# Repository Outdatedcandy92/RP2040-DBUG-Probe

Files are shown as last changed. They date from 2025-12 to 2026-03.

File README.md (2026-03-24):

# RP2040 DBUG Probe

A RP2040 based debug probe; A USB device that provides a UART serial port and SWD interface.
Inspired by the [Raspberry Pi Debug Probe](https://www.raspberrypi.com/documentation/microcontrollers/debug-probe.html) I wanted to make my own debug probe as a fun project but implement custom features like a Type-C connector and regular (non JST) connectors while still keeping the original board footprint.

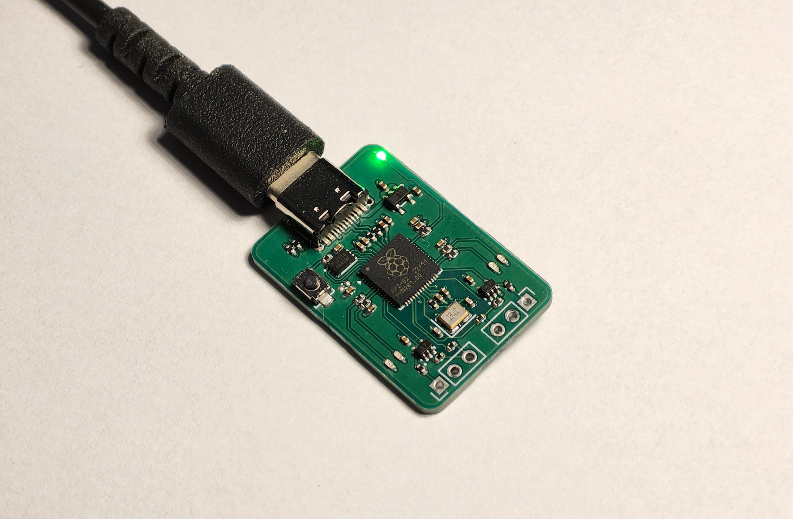
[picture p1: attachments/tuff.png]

## Features

- RP2040 MCU (Duh)
- 16Mbit Flash
- USB-C Connector 
- 32mm X 22mm Board Footprint
- USB to UART/SWD Interfaces With Level Shifters
- Uses regular 2.54mm Pitch Headers
- Status LEDs for serial interfaces and power

## Table of Contents

- [Overview](#rp2040-dbug-probe)
- [Quick Start](#quick-start)
- [Hardware](#hardware)
	- [Pinout](#pinout)
	- [Schematic](#schematic)
	- [PCB](#pcb)
	- [Case](#case)
	- [BOM/Reproduction](#bomreproduction)
- [Firmware](#firmware)
- [License](#license)

## Quick Start

1. Hold the button on the board while plugging in the USB-C cable.
2. The board will appear as a mass storage device.
3. Drag and drop the `debugprobe.uf2` file from `/firmware` onto the device.

The RP2040 will reboot, and the status LED should turn green. It’s now ready to use as a USB-to-UART/SWD bridge.

To use it as a USB-to-UART adapter, open the corresponding COM port in your preferred tool and start communicating.

## Hardware

### Pinout

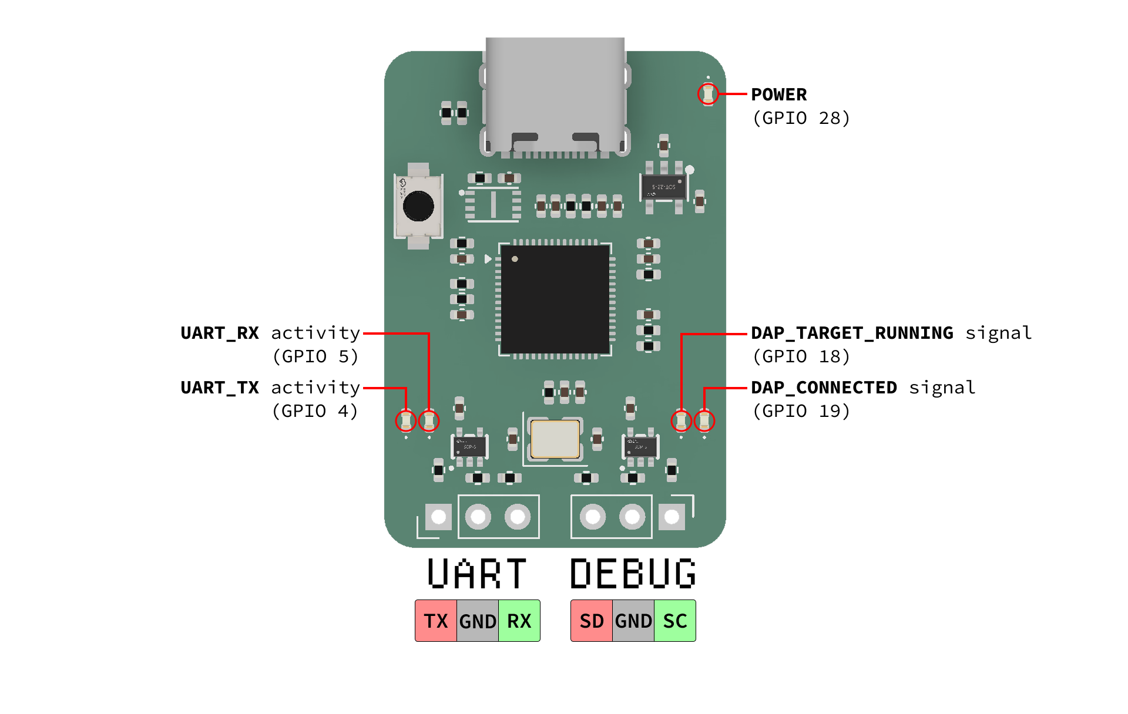
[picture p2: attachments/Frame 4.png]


### Schematic

Schematic pdf is available under the `/hardware/PCB` folder and the project's KiCad files can be found under `/hardware/PCB/kicad`.

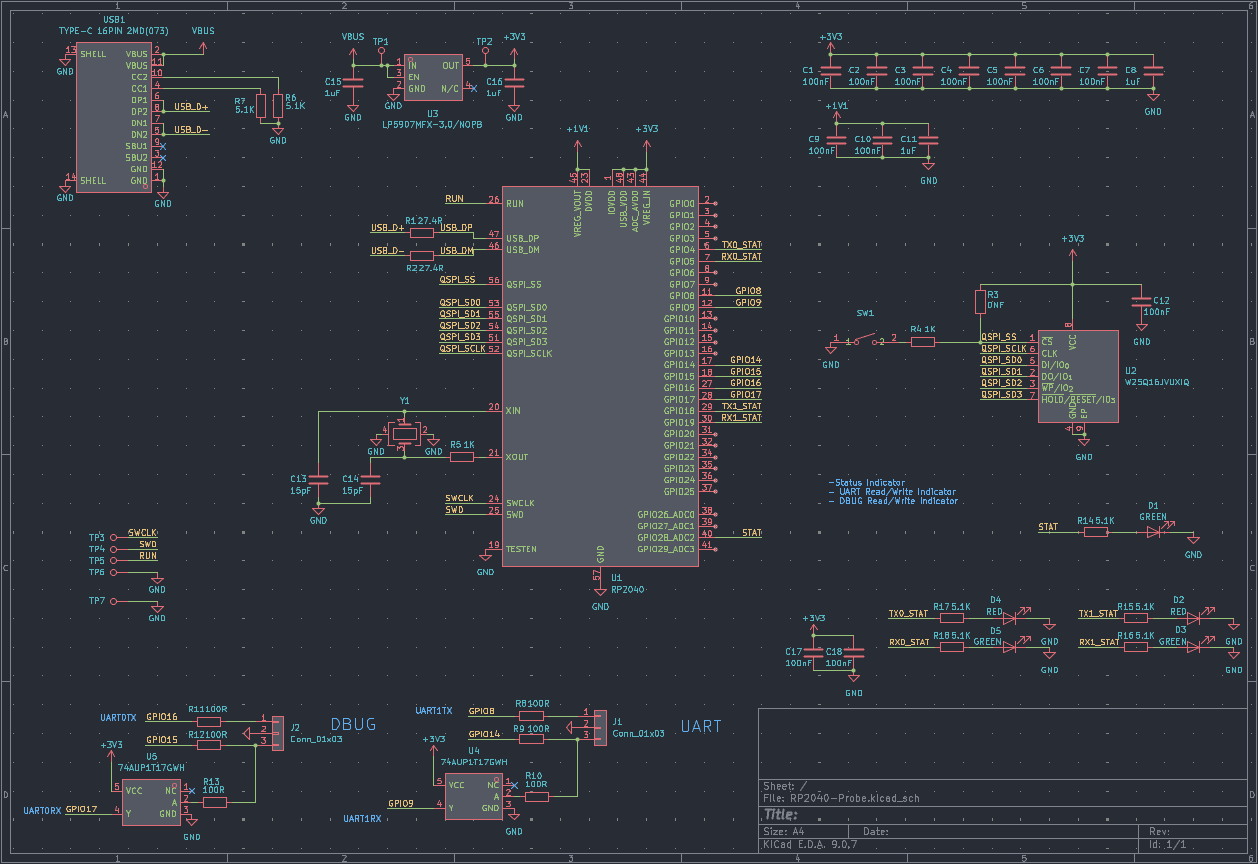
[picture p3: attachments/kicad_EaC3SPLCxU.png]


### PCB

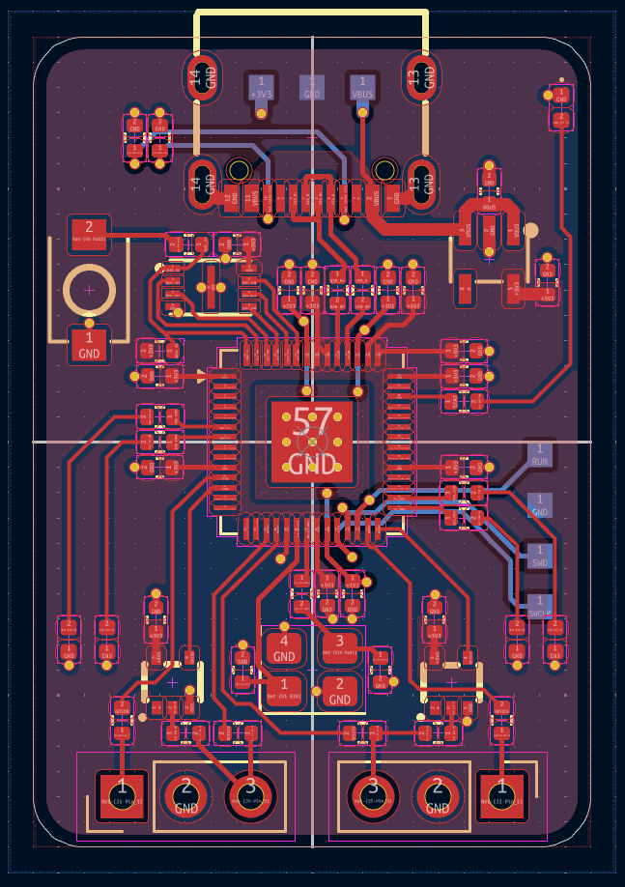
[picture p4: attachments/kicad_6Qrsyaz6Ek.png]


### Case

The case files can be found under `/hardware/case`, It includes the STEP assembly file, and STLs for printing. 
Use the `top.stl` and `logo.stl` if you want to have the logo printed on top, if not use the `top_no_logo.stl`.

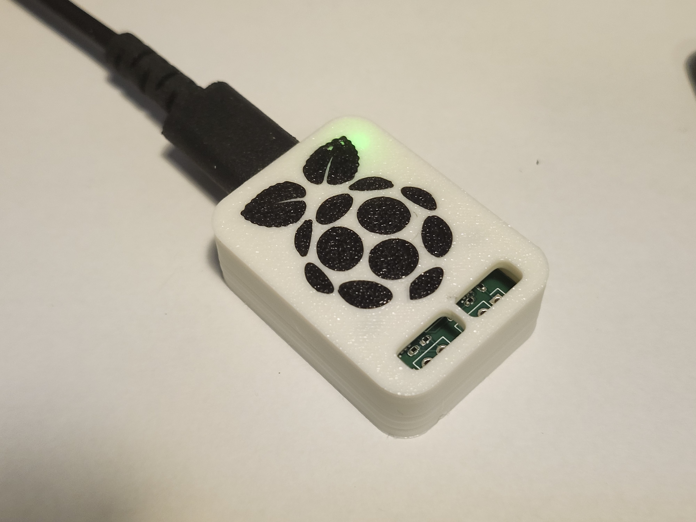
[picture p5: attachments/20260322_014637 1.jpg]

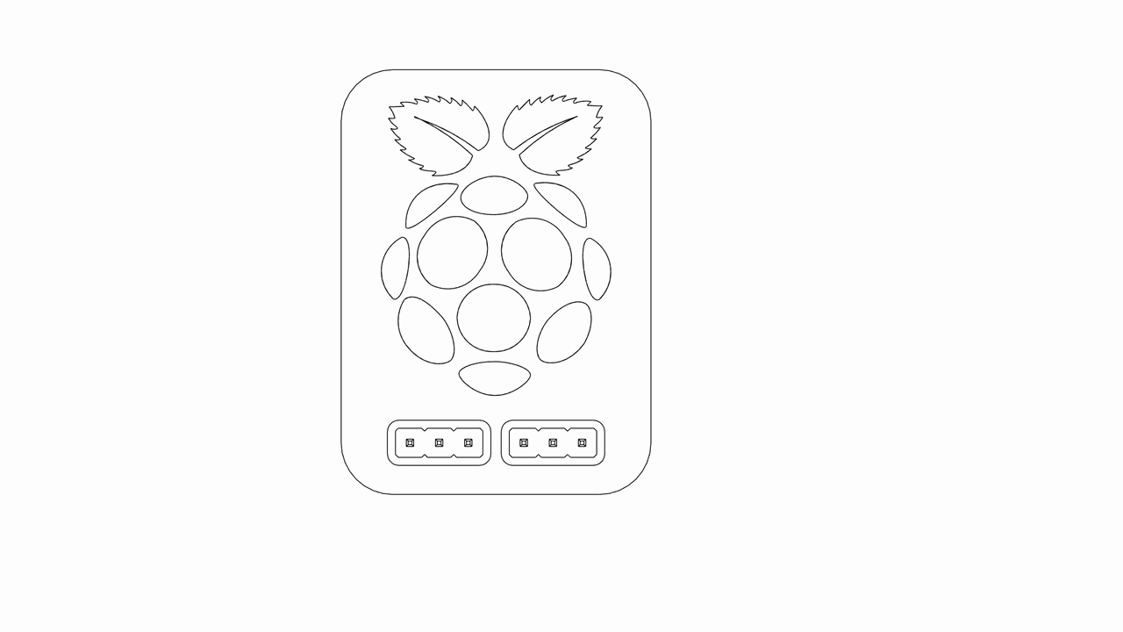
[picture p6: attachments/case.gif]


### BOM/Reproduction

The rough BOM can be found in [BOM.md](./BOM.md) and it assumes you'll assemble the board yourself. The rough cost for just the PCB and parts (excluding shipping) is around $24.

To build one yourself, use the files in `/hardware/production` to order the PCB and components, or opt for PCBA.

## Firmware

This project uses the [Debugprobe](https://github.com/raspberrypi/debugprobe?tab=readme-ov-file) firmware. To build one yourself for this board:

1. Clone the debug probe repository, cd into it and update the submodules.

```
git clone https://github.com/raspberrypi/debugprobe
cd debugprobe
git submodule update --init --recursive
```

2. Open  `/include/board_debug_probe_config.h` and edit the pin definitions to match the board.
   
3. Make a build directory and cd into it.

```
 mkdir build
 cd build
```

4. Run cmake and build the code.

>If your environment doesn't contain `PICO_SDK_PATH`, then either add it to your environment variables with `export PICO_SDK_PATH=/path/to/sdk` or add `-DPICO_SDK_PATH=/path/to/sdk` to the arguments to CMake below.

```
 cmake ..
 make
```

Once it successfully builds you should have a `debugprobe.uf2` file that you can upload to the board.

---

## License

This project is licensed under the CERN Open Hardware Licence Version 2 Weakly Reciprocal [(CERN OHL W)](LICENSE.txt)

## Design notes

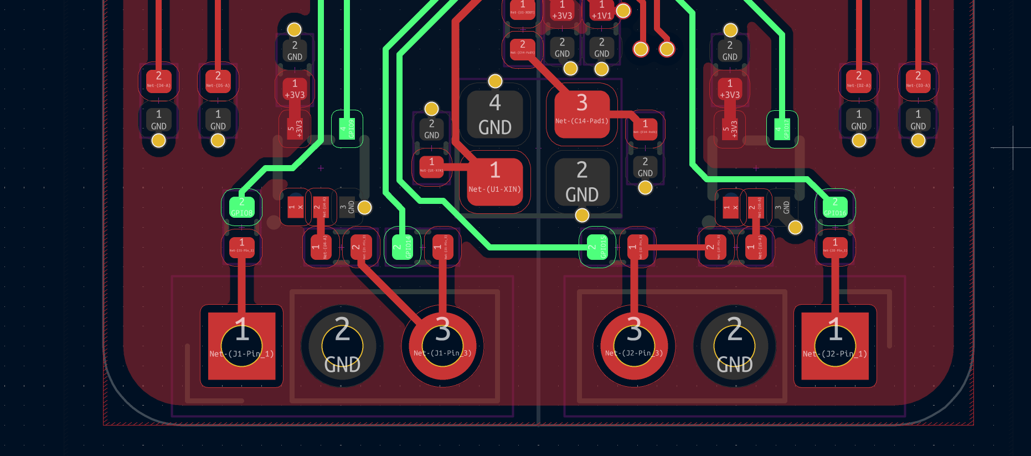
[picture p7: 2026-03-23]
attachments/Screenshot 2025-12-25 191721 1.png

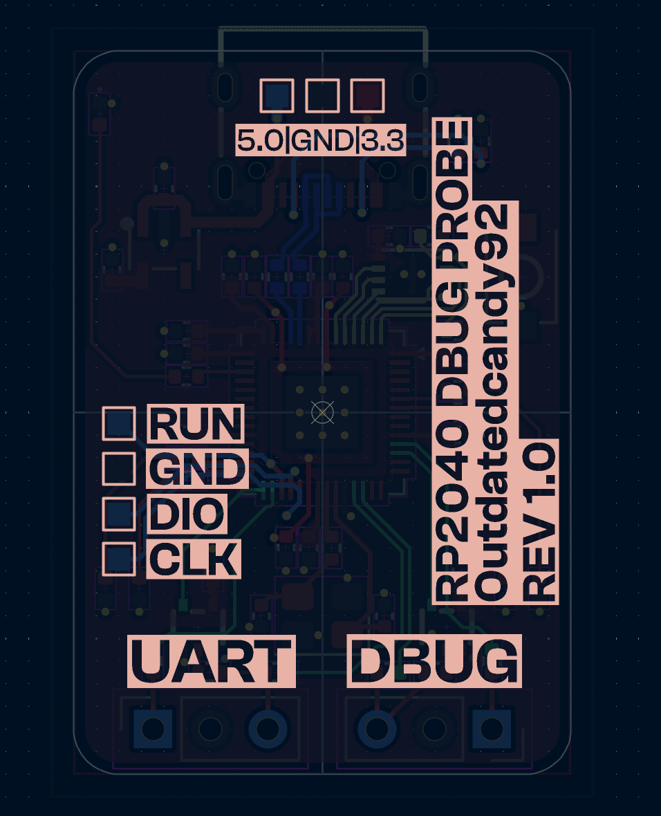
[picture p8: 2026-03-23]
attachments/Pasted image 20251225220737.png

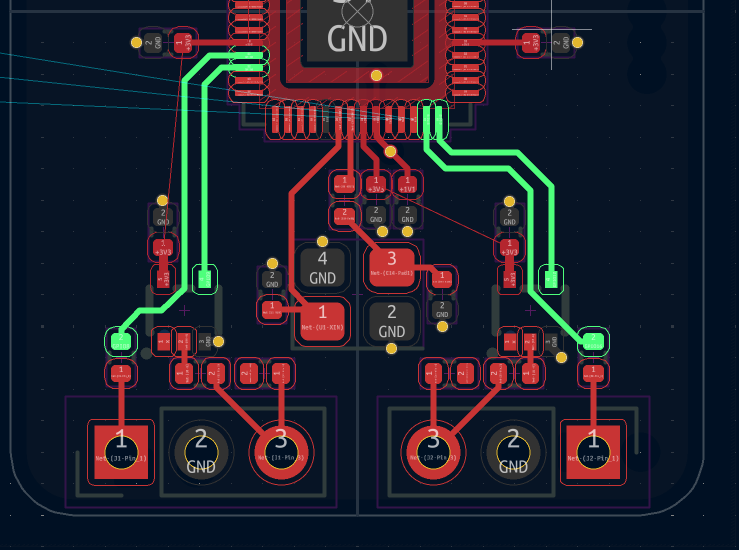
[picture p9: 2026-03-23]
attachments/Screenshot 2025-12-25 174530.png

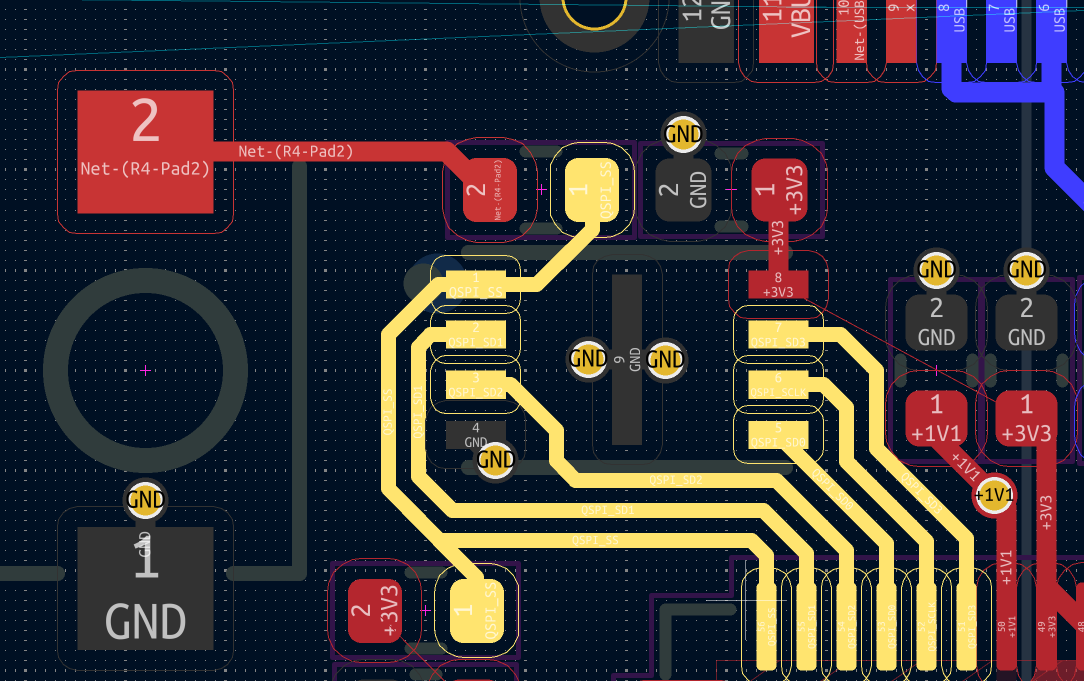
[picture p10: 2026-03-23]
attachments/Screenshot 2025-12-25 165832.png

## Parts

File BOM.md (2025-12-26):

| Name | Description | Quantity | Price  | Shipping |
| --- | --- | --- | --- | --- |
| Componenets | Components from LCSC. Detailed breakdown [here](./PCB/kicad/RP2040-Probe.csv) | - | $16.16 | $13.11 |
| PCB+Stencil | PCB and stencil from JLC | - | $7.10  | $9.79 |
| **Sub Total** | | | $23.26 | $22.9 |
| **Total** | | | $46.16 | |

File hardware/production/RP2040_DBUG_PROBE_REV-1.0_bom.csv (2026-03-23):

Designator | Footprint | Quantity | Value | LCSC Part #
C1, C10, C12, C17, C18, C2, C3, C4, C5, C6, C7, C9 | 0402 | 12 | 100nF
C11, C15, C16, C8 | 0402 | 4 | 1uF
C13, C14 | 0402 | 2 | 15pF
D1, D2, D3, D4, D5 | 0402 | 5 | LED
J1, J2 | PinHeader_1x03_P2.54mm_Vertical | 2 | Conn_01x03
R1, R2 | 0402 | 2 | 27.4R
R10, R11, R12, R13, R8, R9 | 0402 | 6 | 100R
R14, R15, R16, R17, R18, R6, R7 | 0402 | 7 | 5.1K
R3 | 0402 | 1 | DNF
R4, R5 | 0402 | 2 | 1K
SW1 | SW-SMD_L3.9-W3.0-P4.45 | 1 | TS-1088-AR02016 | C720477
TP1, TP2, TP3, TP4, TP5, TP6, TP7 | TestPoint_Pad_1.0x1.0mm | 7 | TestPoint
U1 | QFN-56-1EP_7x7mm_P0.4mm_EP3.2x3.2mm | 1 | RP2040
U2 | USON-8_L3.0-W2.0-P0.50-BL-EP | 1 | W25Q16JVUXIQ
U3 | SOT-23-5_L3.0-W1.7-P0.95-LS2.8-BL | 1 | LP5907MFX-3.3/NOPB | C80670
U4, U5 | TSSOP-5_L2.1-W1.3-P0.65-LS2.2-BR | 2 | 74AUP1T17GWH | C545951
USB1 | USB-C-SMD_TYPE-C-6PIN-2MD-073 | 1 | TYPE-C 16PIN 2MD(073) | C2765186
Y1 | Crystal_SMD_Abracon_ABM8G-4Pin_3.2x2.5mm | 1 | Crystal_GND24

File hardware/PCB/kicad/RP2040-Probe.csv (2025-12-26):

Reference | Qty | Value | LCSC Part | Footprint
C1,C2,C3,C4,C5,C6,C7,C9,C10,C12,C17,C18 | 12 | 100nF | C77020 | Capacitor_SMD:C_0402_1005Metric
C8,C11,C15,C16 | 4 | 1uF | C1518208 | Capacitor_SMD:C_0402_1005Metric
C13,C14 | 2 | 15pF | C441742 | Capacitor_SMD:C_0402_1005Metric
D1,D3,D5 | 3 | GREEN | C965793 | LED_SMD:LED_0402_1005Metric
D2,D4 | 2 | RED | C25503345 | LED_SMD:LED_0402_1005Metric
J1,J2 | 2 | Conn_01x03 | C52016391 | Connector_PinHeader_2.54mm:PinHeader_1x03_P2.54mm_Vertical
R1,R2 | 2 | 27.4R | C31439 | Resistor_SMD:R_0402_1005Metric
R3 | 1 | DNF | - | Resistor_SMD:R_0402_1005Metric
R4,R5 | 2 | 1K | C11702 | Resistor_SMD:R_0402_1005Metric
R6,R7,R14,R15,R16,R17,R18 | 7 | 5.1K | C25905 | Resistor_SMD:R_0402_1005Metric
R8,R9,R10,R11,R12,R13 | 6 | 100R | C25076 | Resistor_SMD:R_0402_1005Metric
SW1 | 1 | TS-1088-AR02016 | C720477 | easyeda2kicad:SW-SMD_L3.9-W3.0-P4.45
TP1,TP2,TP3,TP4,TP5,TP6,TP7 | 7 | TestPoint | - | TestPoint:TestPoint_Pad_1.0x1.0mm
U1 | 1 | RP2040 | C2040 | Package_DFN_QFN:QFN-56-1EP_7x7mm_P0.4mm_EP3.2x3.2mm
U2 | 1 | W25Q16JVUXIQ | C2843335 | easyeda2kicad:USON-8_L3.0-W2.0-P0.50-BL-EP
U3 | 1 | LP5907MFX-3.0/NOPB | C475492 | easyeda2kicad:SOT-23-5_L3.0-W1.7-P0.95-LS2.8-BL
U4,U5 | 2 | 74AUP1T17GWH | C545951 | easyeda2kicad:TSSOP-5_L2.1-W1.3-P0.65-LS2.2-BR
USB1 | 1 | TYPE-C 16PIN 2MD(073) | C2765186 | easyeda2kicad:USB-C-SMD_TYPE-C-6PIN-2MD-073
Y1 | 1 | Crystal_GND24 | C20625731 | Crystal:Crystal_SMD_Abracon_ABM8G-4Pin_3.2x2.5mm

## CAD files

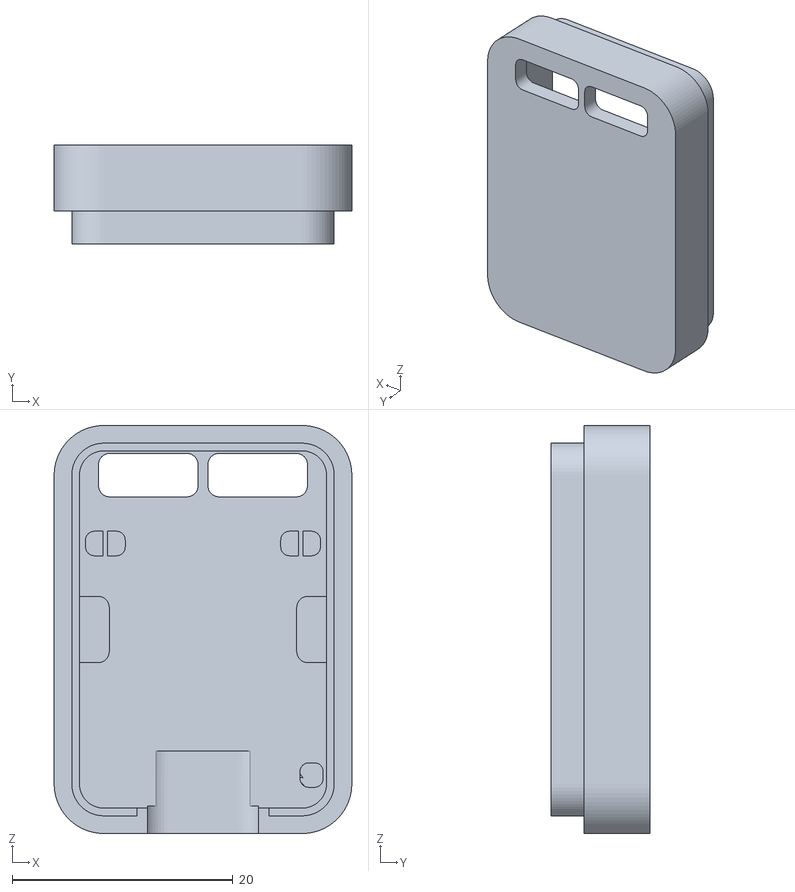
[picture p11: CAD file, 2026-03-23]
hardware/case/STLs/top_no_logo.stl
27.0 x 9.00 x 37.0

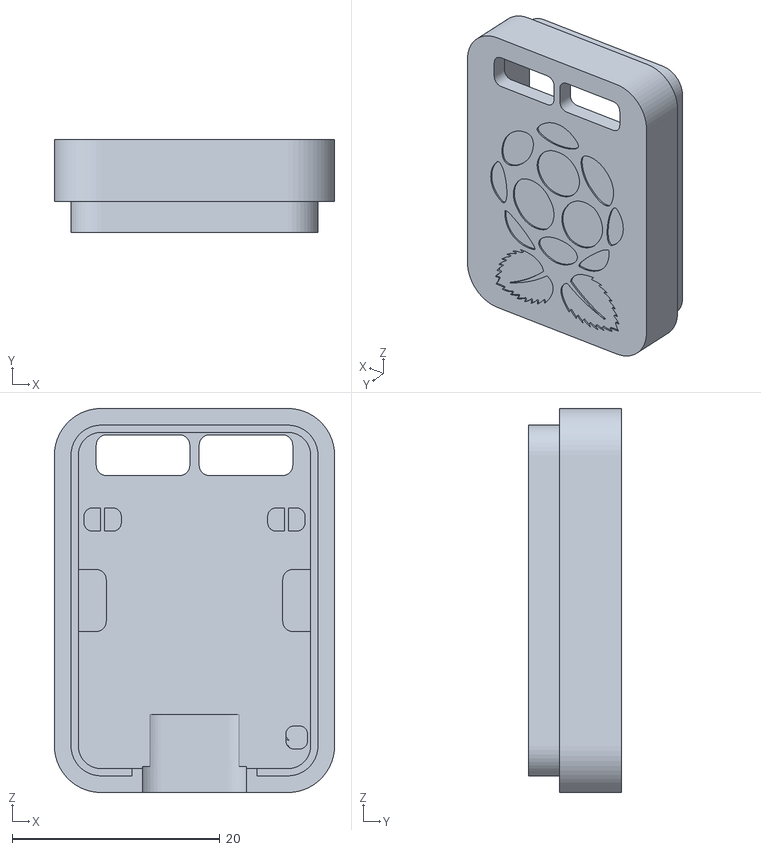
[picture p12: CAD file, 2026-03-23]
hardware/case/STLs/top.stl
27.0 x 9.00 x 37.0

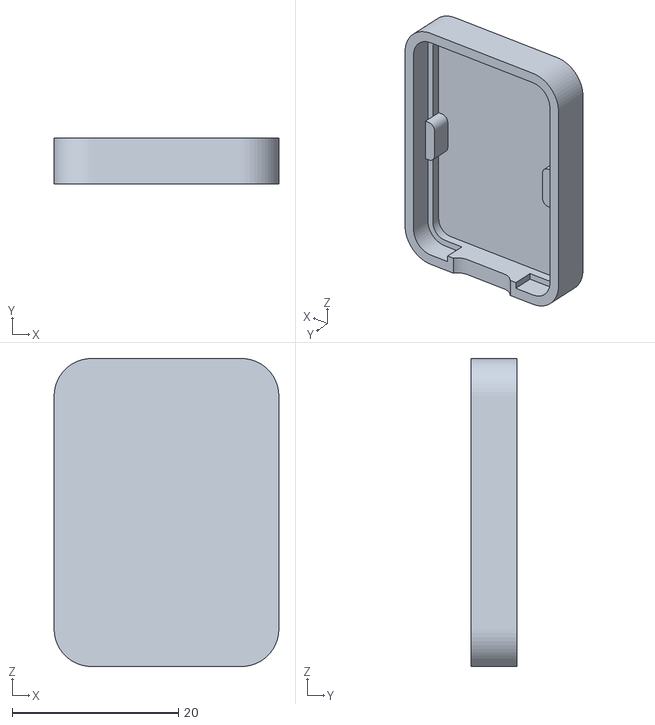
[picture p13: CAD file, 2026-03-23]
hardware/case/STLs/bottom.stl
27.0 x 5.51 x 37.0

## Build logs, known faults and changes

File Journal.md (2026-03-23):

# RP2040 DBUG Probe

> Some images in the journal are unavailable due to a CDN issue. 

## 25 December, 2025 - Designing The PCB

I broke my old UART to USB adapter and recently saw an article about the [Raspberry Pi Debug Probe](https://www.raspberrypi.com/documentation/microcontrollers/debug-probe.html) and though why not make one myself 🤔

So that's exactly what I did; I started off with just researching about the Debug probe and was figuring out how exactly to execute this project, and luckily for me the schematics were open sourced for the debug probe. 
It was a really simple board with just a RP2040, some passive, a LDO and headers!! And so the journey began, I started off with the minimal RP2040 schematics which I copied off the hardware design guide, and then all I really needed to do was to add the connectors. At this point in time I referred to the Debug probe schematics and noticed that they actually included a level shifter on the RX lines of the boards, so I just decided to copy their schematics; but here's where things started getting bad, KiCad started bugging out for me, it was no longer detecting new symbols added using easyeda2kicad and that really slowed me down. I spent 30 minutes trying to solve the issue with no success, In the end I decided to reinstall easyeda2kicad and delete the old symbol and footprint folders; This initially did not work but after restarting my computer and KiCad everything started to work and I could finally finish up my schematics.



Moving on to the PCB; first step was to setup the board outline, I went with the original raspberry pi debug probe board dimensions of 22x32mm which I got from their mechanical drawing.




While doing the layout I decided to assign some net classes and color code them to visualize the layout better.





Routing the board was pretty fun. I did however had to reroute the QSPI flash traces a couple dozen times cause I kept changing the layout.



Pro Tip to anyone who's doing a RP2040/RP2350 or honestly any design where the chip more than one rail; go with a power pour as shown below. Make the outer fill region be 3v3 or whatever has the most pins and let the inner pour be the one with less pins.



Here's some routing progression pictures :D







I went with a 3V3 pour on top and a ground plane on the bottom layer, I also tried my best to keep a solid ground plane and avoid routing anything on the bottom layer, since this was a pretty easy board I managed to route everything on just two layers (this is my first 2 layer board in a very long time).

This is how the board looked after I finished routing everything up





image|60

Now all that was left to do was add some testpoints and silkscreen. I added test points for the voltage rails and the swd interface of the rp2040 itself as I couldn't route it out to some headers. For silkscreen I just added some labels for the pin headers and test points and yeah that was it, didn't really add anything as this was a pretty small board, though I might add the oshw logo on this later.



I was basically done now! all that was left to do was to get the production files and setup a github repo; but before that we must run DRC and well uh 



It's not as bad as it looks though, most of these were because I forgot to change the default  constraints in KiCad and the rest were errors because of the hole in the USB-C footprint which I just excluded.

Finished everything up by assigning lcsc numbers to components and generating a BOM



### Time Spent: 6.5 Hours
---
## 20 March, 2026  - Assembled The Board

I finally had some free time today and I didn't procrastinate and decided to finally assemble the board.

Started off by generating an interactive HTML BOM using the KiCad plugin and then used that to basically get all the components required for this out.

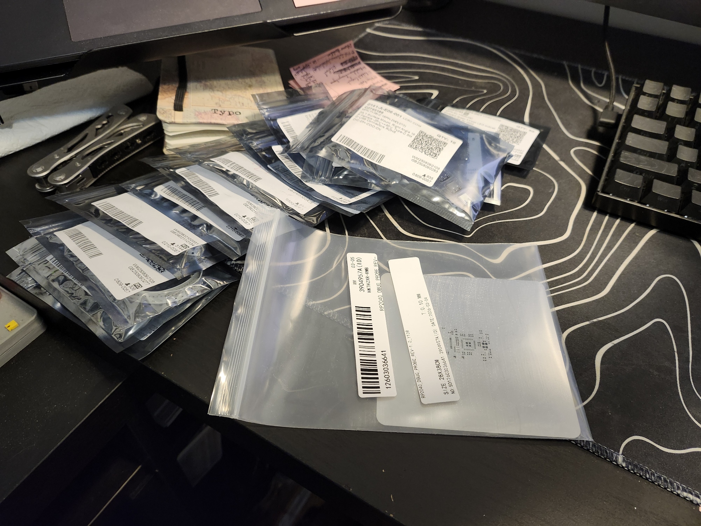
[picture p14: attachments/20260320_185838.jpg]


Then I went ahead and applied solder paste on the board using a stencil. It only took me about 3 tries to get the perfect amount of solder evenly on the board.

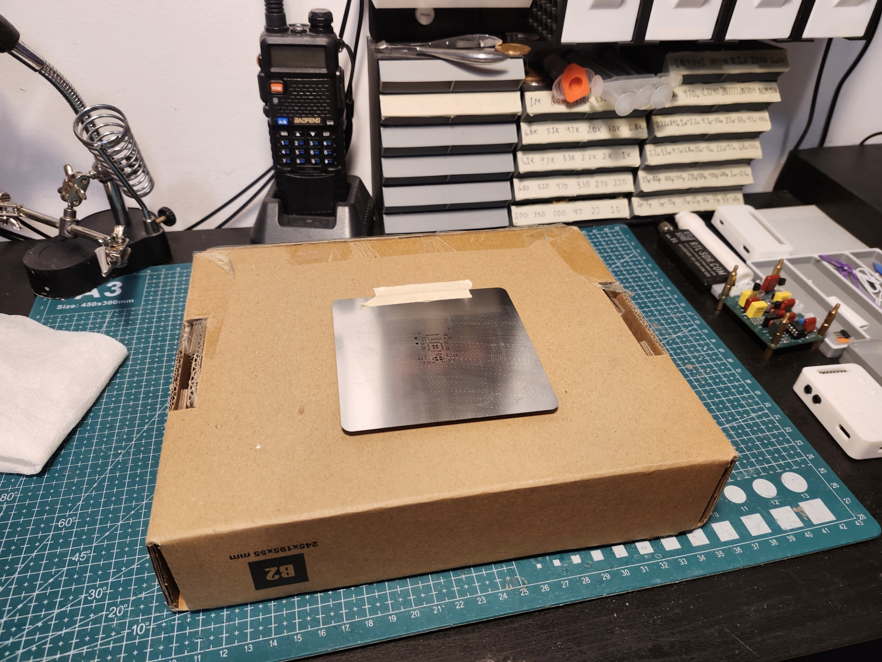
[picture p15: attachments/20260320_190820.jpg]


Then it was just the tedious task of picking and placing the small 0402 passives and componenets.

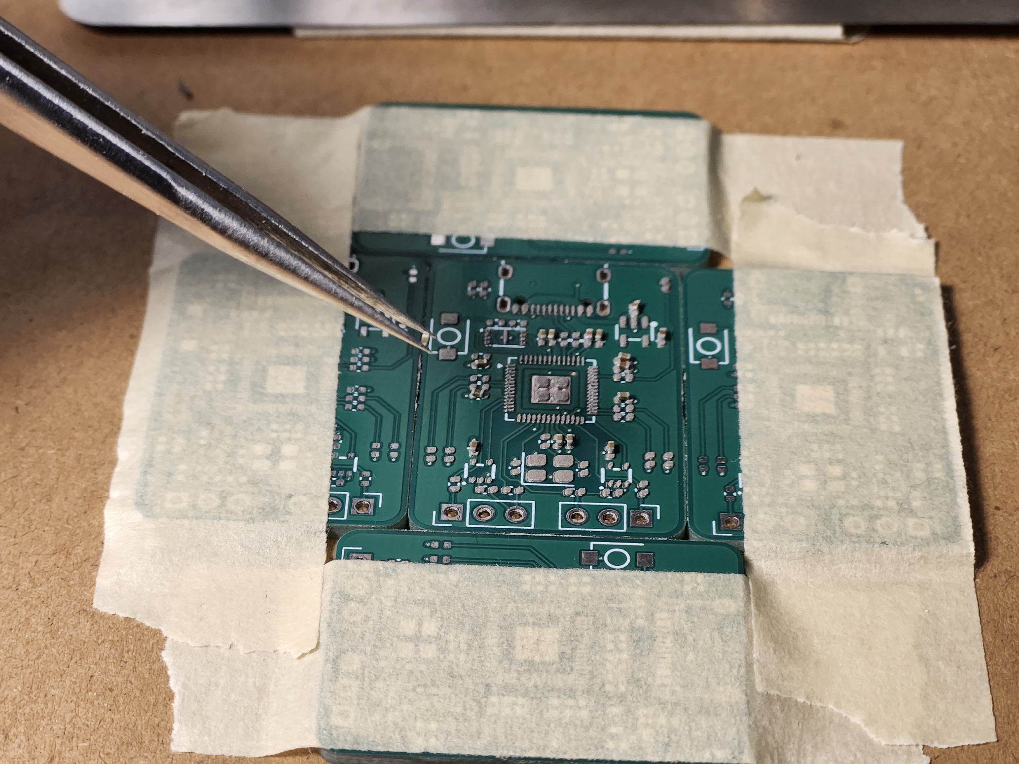
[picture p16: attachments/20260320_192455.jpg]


After everything was placed, the board was sent to the reflow plate, where it got cooked. After getting cooked, I visually inspected all the pads to check if there were any bridges, luckily there weren't any. Though there was a tiny blob of solder on one of the RP2040 pads (It didn't short anything), so I just put some flux, and got out the pinecil with knife tip and remove the extra solder.

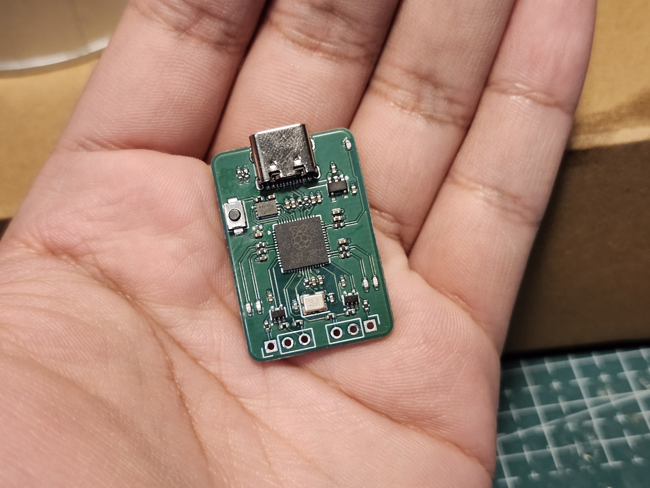
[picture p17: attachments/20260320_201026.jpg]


I was going to plug in the board to a usb connector, but I saw that the USB-C port was a bit shaky and it would have probably gotten ripped off if I tried to plug in anything. So I just soldered up it's mounting holes and plugged it in. 

It showed up as a RPI-RP2 which was a good sign, I flashed circuitpython on it and wrote minimal code to get one of the LED to light up and it worked :D



I quickly wrote an LED chaser effect script to test out all the LEDs, and it worked successfully.



### Time Spent: 2 Hours
---
## 21 March, 2026 - Developing Firmware

For firmware I decided to go with using the raspberry pi [Debugprobe](https://github.com/raspberrypi/debugprobe) firmware. They made it open source and it was really easy to modify it for my board.

I initially tried building it on windows but that was pretty frustrating as I had no tools installed, and it just feels weird. So I installed debian on WSL and cloned the Debugprobe repo on that, installed the pico-sdk and then modified the `board_debug_probe_config.h` file under the `include` folder with the pin definitions for my board and then built it. 

I got my `.uf2` and I flashed the RP2040 with it and everything worked perfectly :D

I loaded up teraterm to open the COM port and type something to check if it works properly, and sure enough I see a red LED blink when I send something. Although the LED was on the wrong side (that's what I though), because the silkscreen on the bottom said this was the SWD interface and not UART. So I rebuilt the firmware, and then hopped on KiCad to fix the labels, and that's when I realized that my labels were actually correct, but I had just messed up on the silkscreen. So I reverted back to the original build lmao.

After finishing firmware I went ahead and started polishing the repository, started off by making a cool pinout thingamajig in figma.
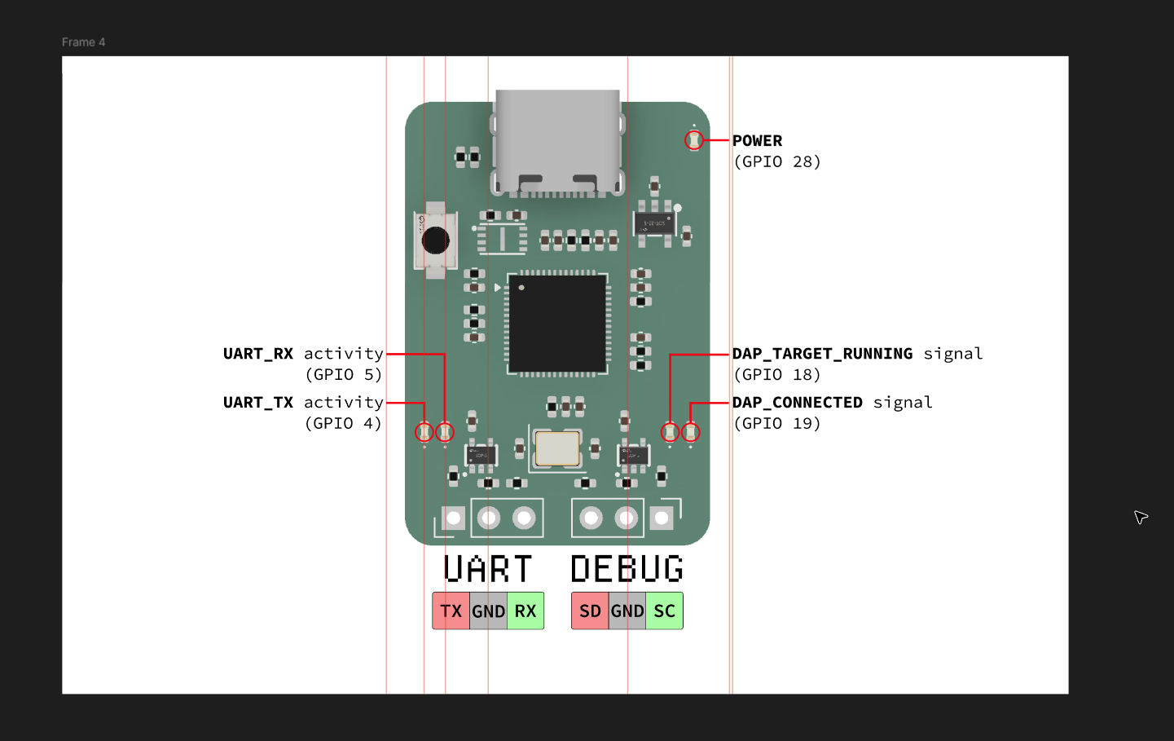
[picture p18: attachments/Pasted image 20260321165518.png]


While here I also decided to make a case for it cause why not. The problem I faced was that this PCB had no mounting holes so I can't make a screw on design.

I first started off with a slide in design where the PCB can slide into a tight gap to remain secured but scrapped that as It was a pretty weird thing to implement in fusion and in the end it didn't even look cool.

*scrapped slide in case idea*
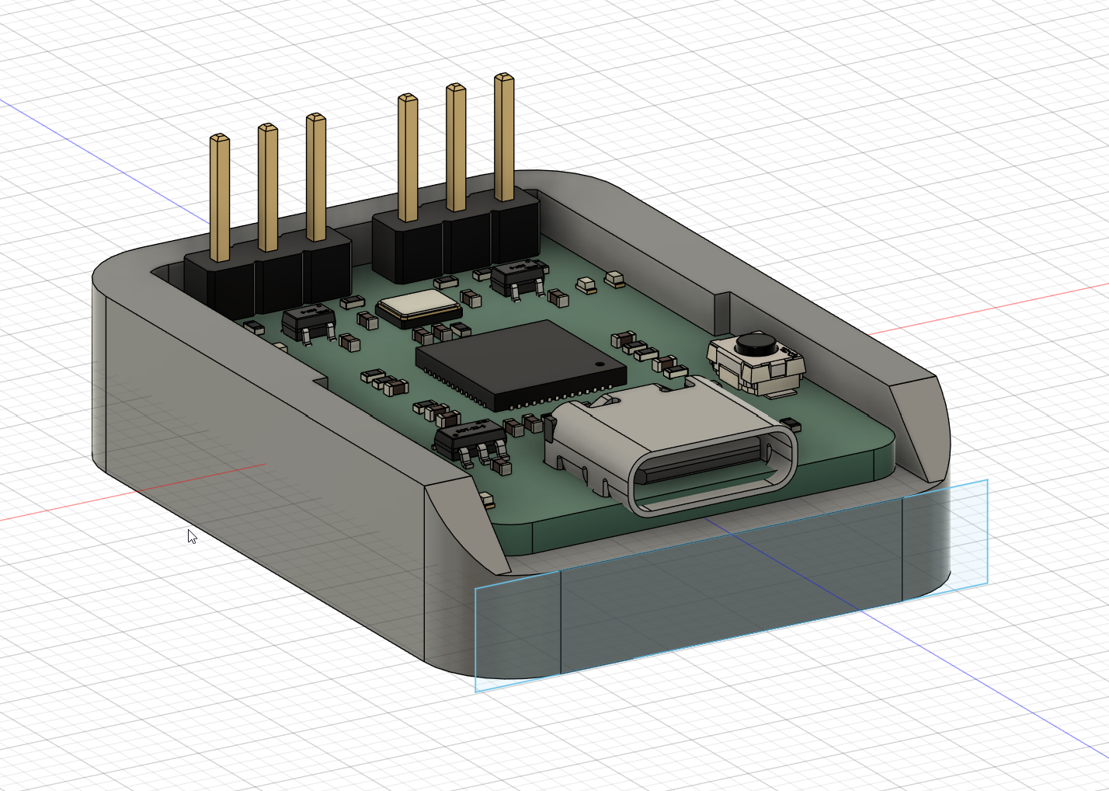
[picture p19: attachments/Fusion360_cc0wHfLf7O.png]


So I went ahead and decide to create a tiny snap fit/press fit type of case.

Started off by just creating like an enclosure and splitting it into two parts.

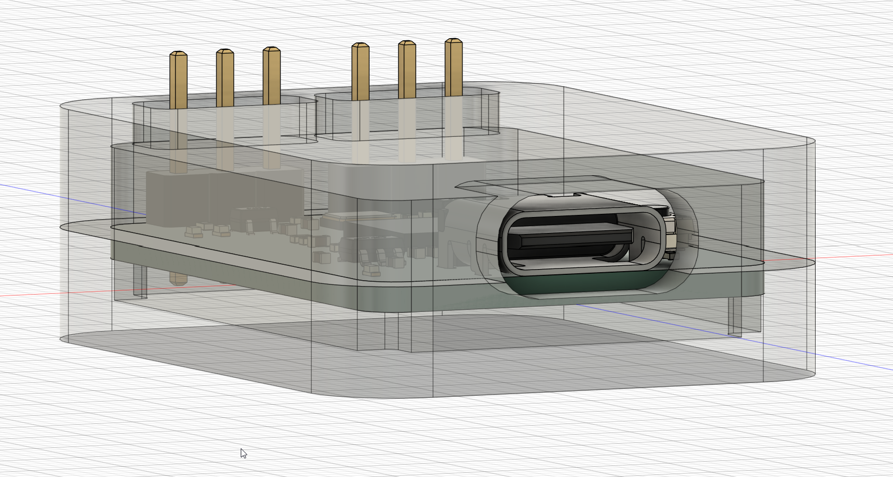
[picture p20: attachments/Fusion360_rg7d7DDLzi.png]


I then extruded a part of the top case down into the bottom part and then cut it out from the bottom part.

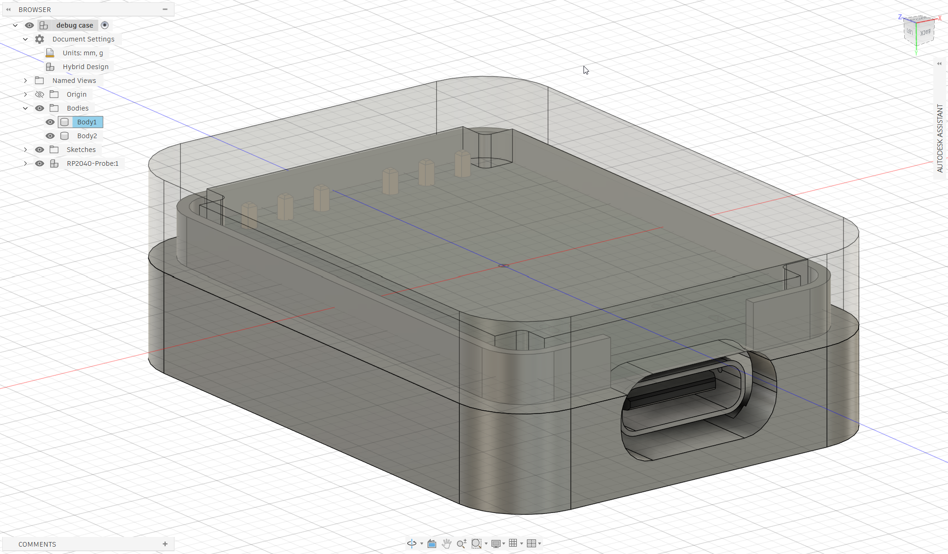
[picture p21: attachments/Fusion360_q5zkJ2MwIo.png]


I added 0.2mm offsets to everything to account for printer tolerance and then printed a draft version which fit together pretty good.

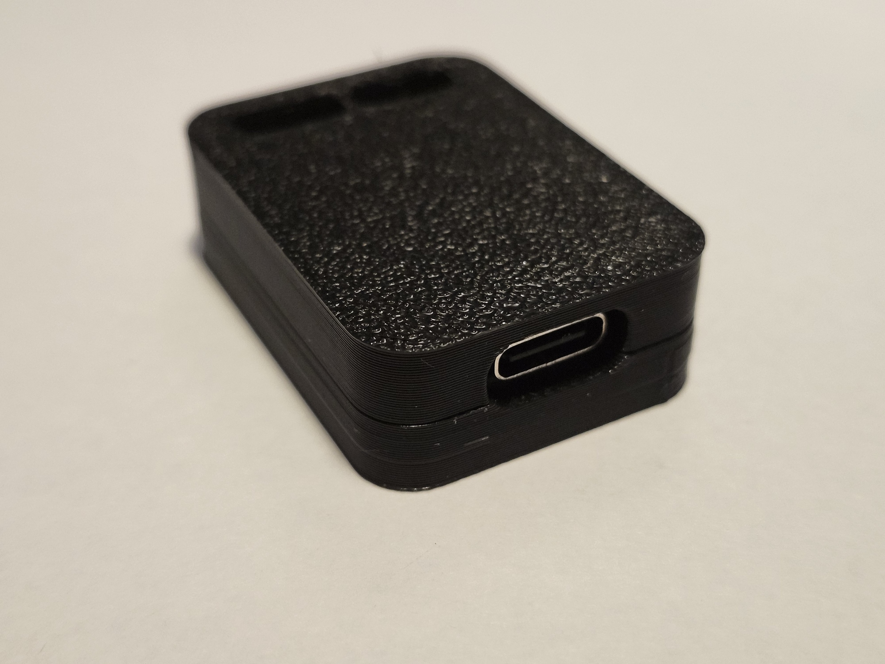
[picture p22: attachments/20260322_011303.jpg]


Knowing that the press fit design works, I added more features like these two extrusions you see in the middle to pinch the PCB and ensure it doesn't rotate inside the case.

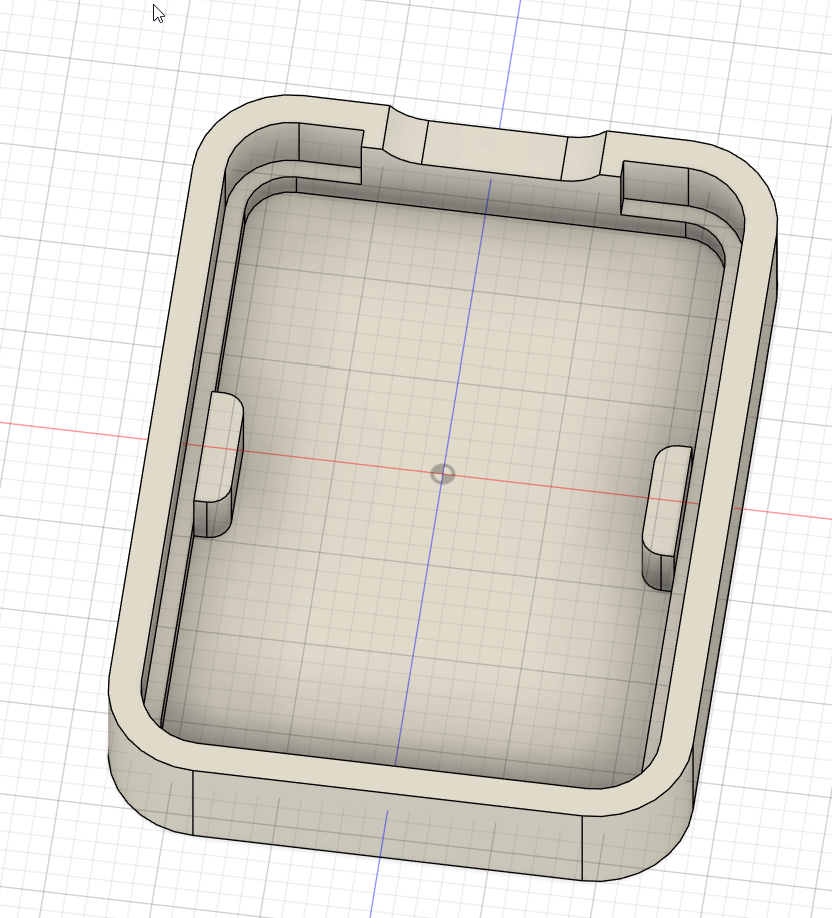
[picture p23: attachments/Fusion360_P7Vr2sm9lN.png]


On the top part I added these hollow parts in the wall right above where the LEDs are so they could be seen through the plastic.

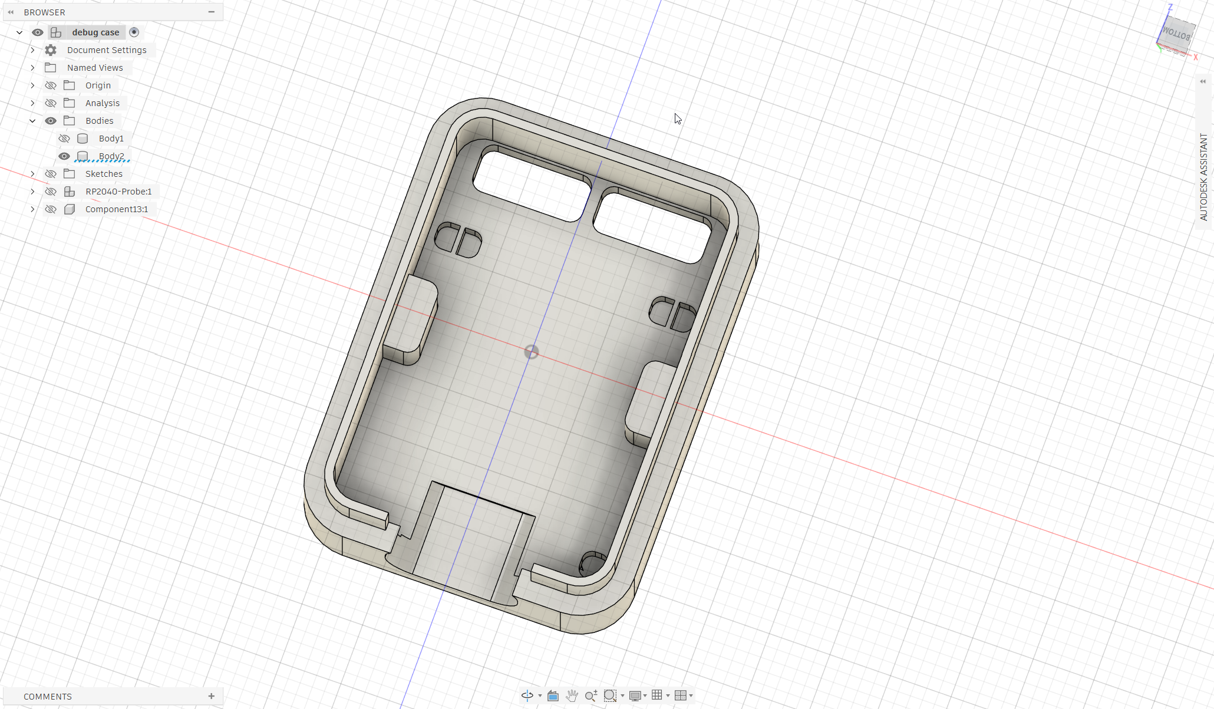
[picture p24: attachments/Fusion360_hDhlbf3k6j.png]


And after that I did a bunch of tries to get a raspberry pi logo on the top case.

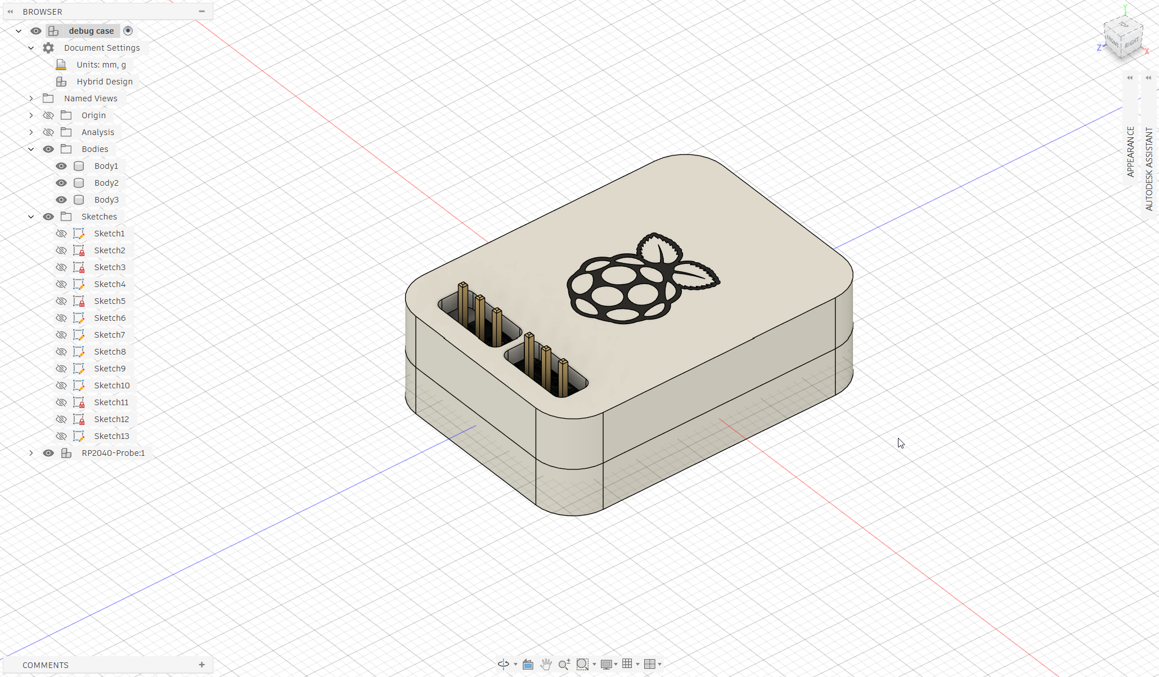
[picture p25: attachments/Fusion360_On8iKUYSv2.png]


This one had the logo too small so it couldn't print properly, I tried resizing and exporting a few different times to look in the slicer and nothing really worked (well). So I decided to actually negative of the shape and extrude that into black so its easier to print.

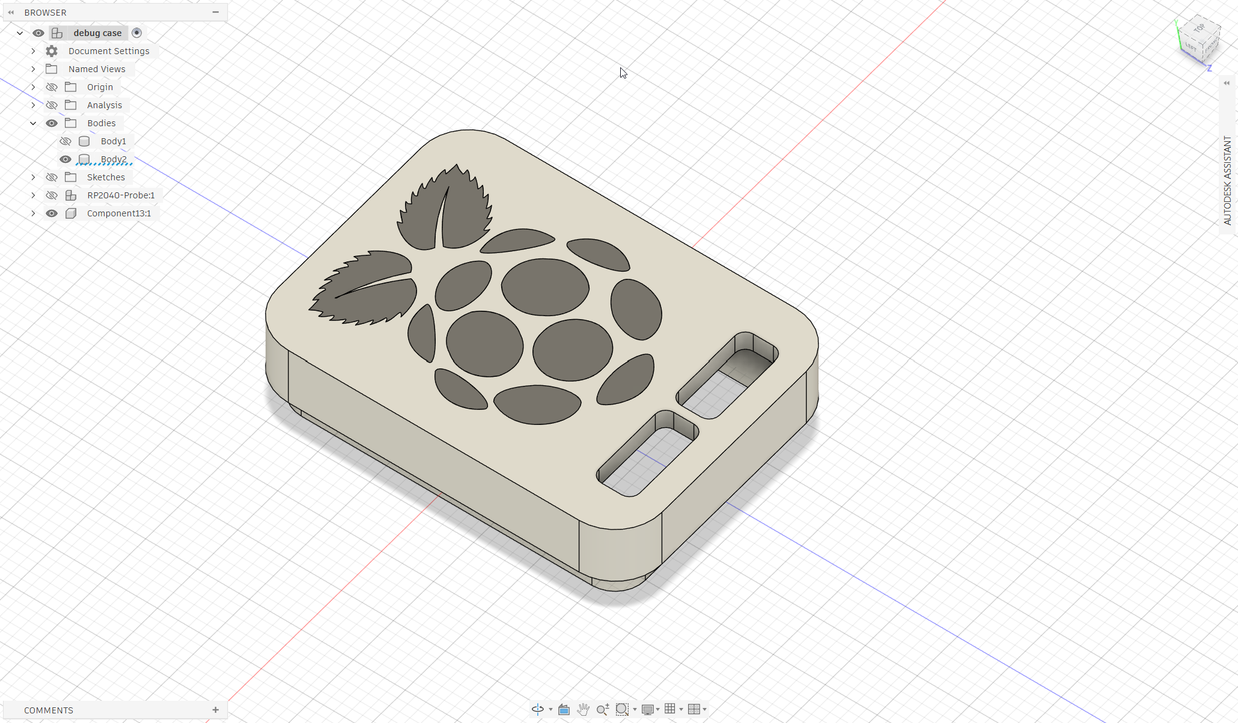
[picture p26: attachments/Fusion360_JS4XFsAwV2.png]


I spent like a solid 20 minute in Bambu Studio trying to figure out how to print this without an AMS and I was stuck trying to figure out how to get the black part to print first and not the white. I kept searching in parts setting but it eventually turns out you can set the sequence by clicking on the gear icon that shows up next to the build plate.

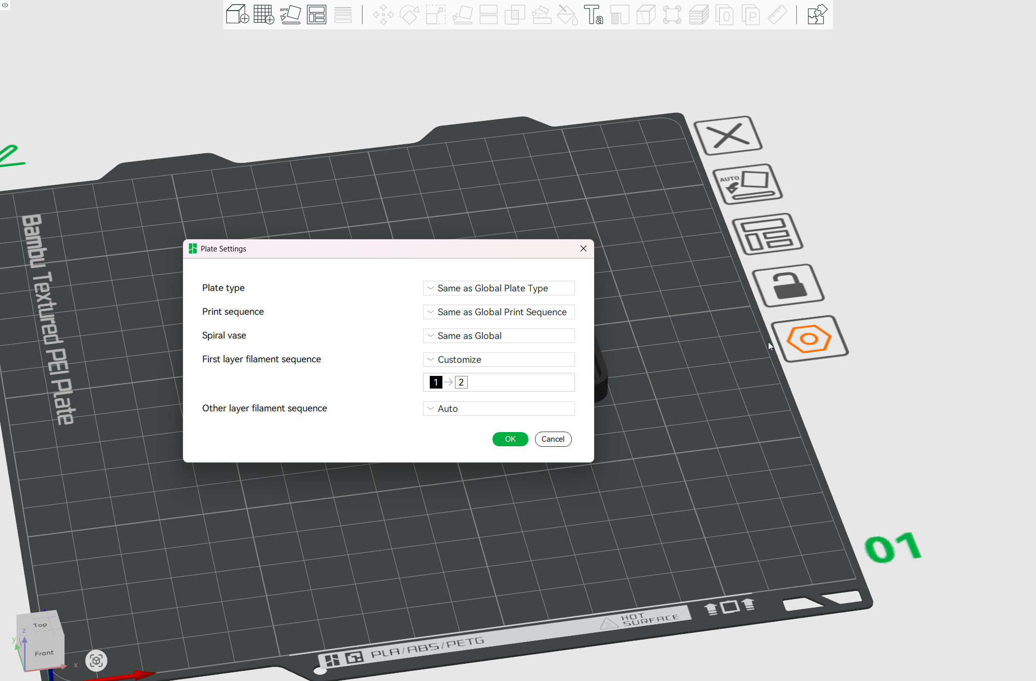
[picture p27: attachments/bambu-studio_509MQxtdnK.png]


this is what my top printed case looked like irl.

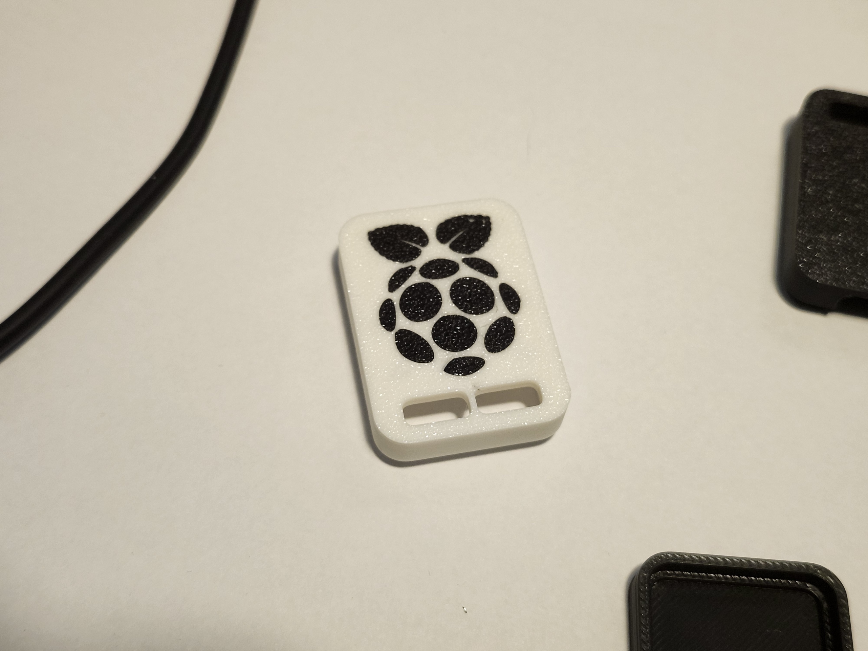
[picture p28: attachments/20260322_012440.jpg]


pretty sick!

I put the debug probe PCB inside the case and plugged it in but nothing happened. I was kinda scared but it took me a while to realize the USB-C connector was a bit loose and that was causing the problem.

So I threw the board back onto the reflow board to fix the connections, but as I was taking it off It slipped and fell on the ground. This was actually painful and my heart dropped, fortunately due to surface tension most of the components stayed on the board. Only the USB-C connector, Crystal and the LDO fell off which I reflowed back on. For good measure I soldered my USB-C connectors' mounting holes with better leaded solder compared to the bismuth solder. While here I also noticed that my RP2040 had a bridged pin so I fixed that with a knife tip pinecil and some flux.

I plug it back in an voila it works :D



### Time Spent: 3 Hours

---
## 22 March, 2026 - Polishing Repo

I basically just polished up the repository today, added all the new CAD files, improved the README and added firmware and case sections.

I also did a little case animation in Fusion360 which looks pretty cool.



Also did some writeups for reddit posts which I'm going to make tomorrow.

### Time Spent: 1 Hour

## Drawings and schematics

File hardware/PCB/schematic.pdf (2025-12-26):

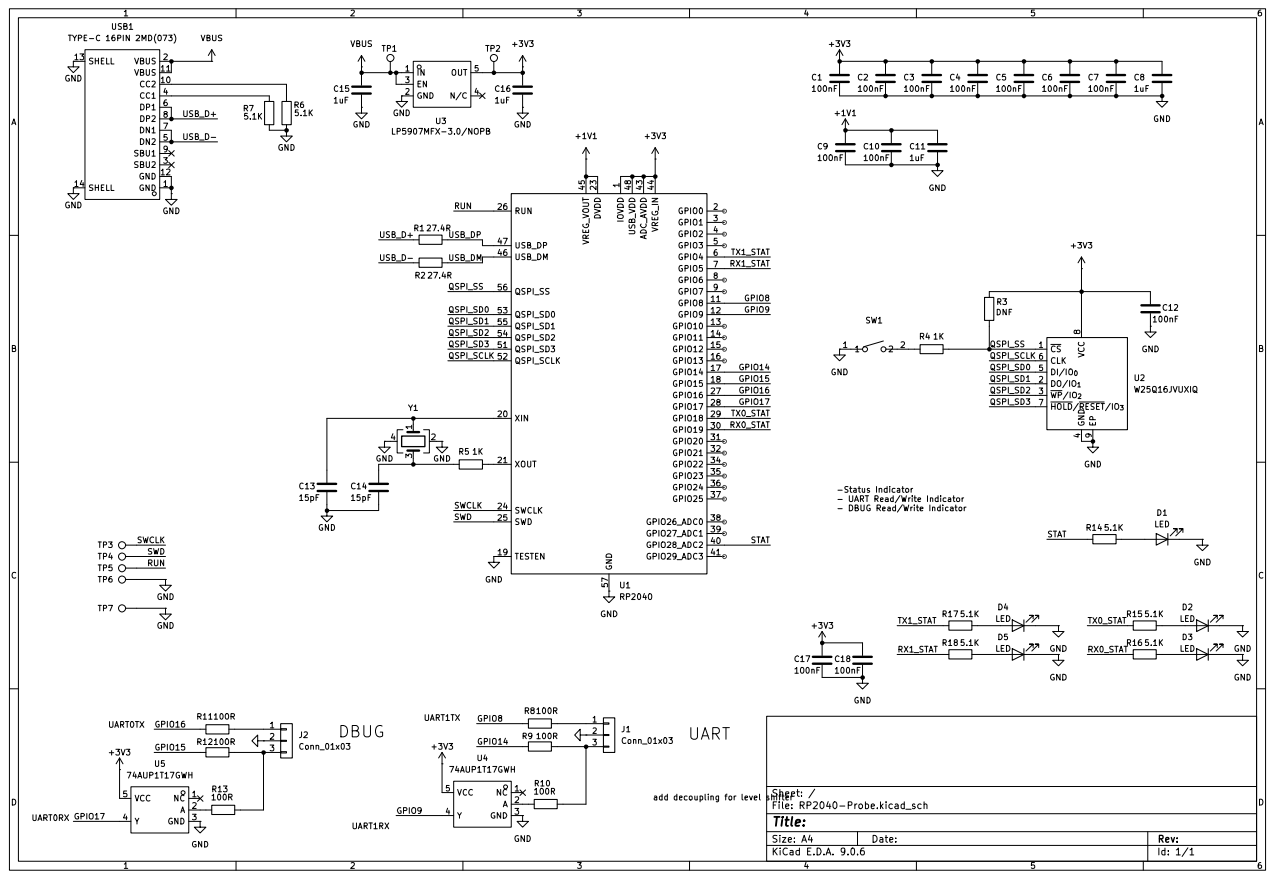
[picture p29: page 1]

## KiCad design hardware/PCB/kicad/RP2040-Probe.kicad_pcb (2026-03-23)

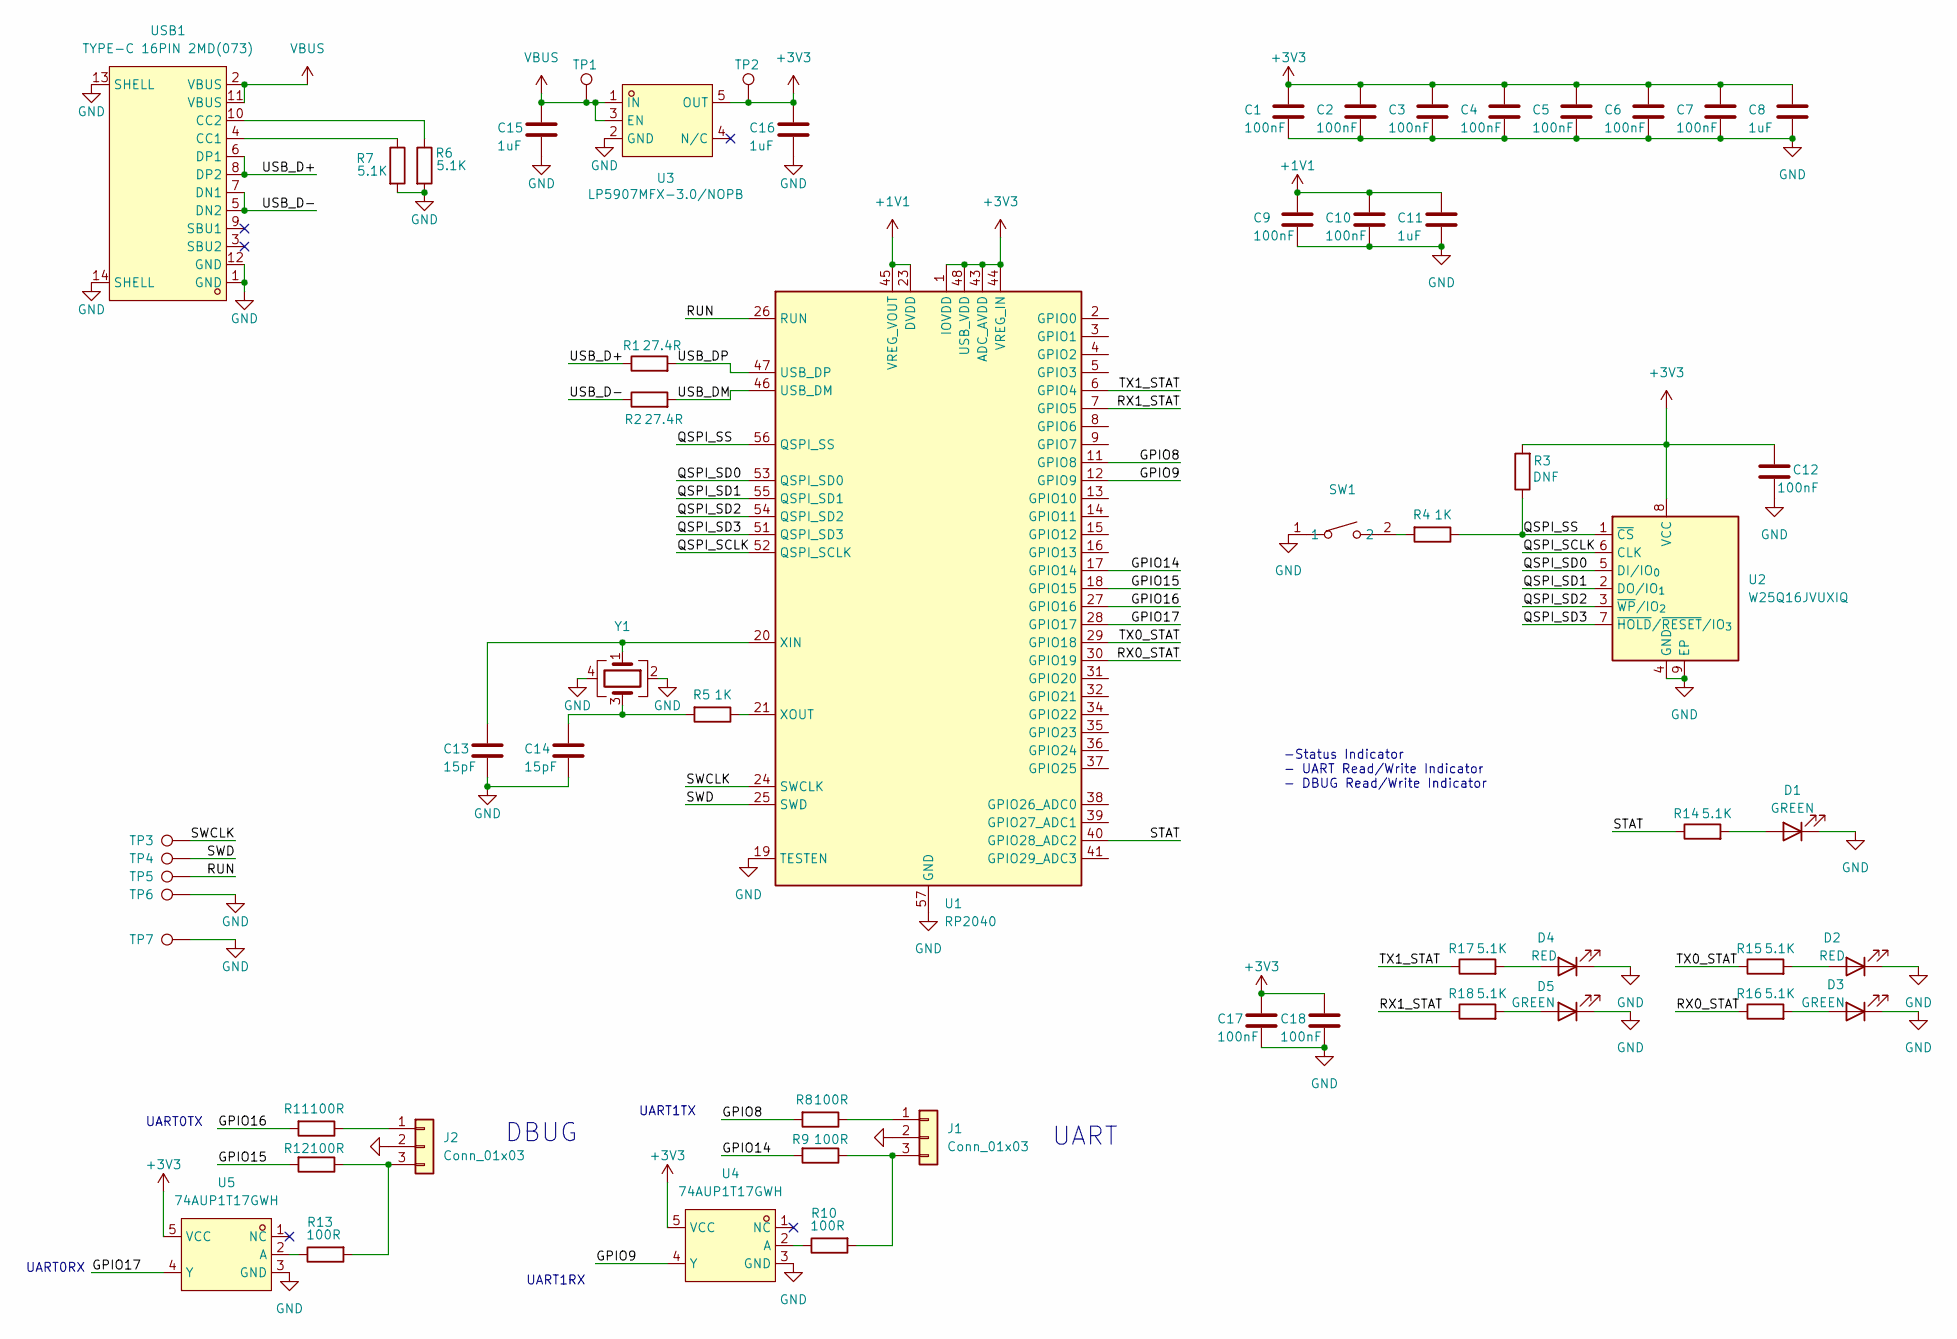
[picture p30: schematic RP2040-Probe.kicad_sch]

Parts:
C1, C2, C3, C4, C5, C6, C7, C9, C10, C12, C17, C18: 100nF; C_0402_1005Metric; LCSC Part C77020
C8, C11, C15, C16: 1uF; C_0402_1005Metric; LCSC Part C1518208
C13, C14: 15pF; C_0402_1005Metric; LCSC Part C441742
D1, D3, D5: GREEN; LED_0402_1005Metric; LCSC Part C965793
D2, D4: RED; LED_0402_1005Metric; LCSC Part C25503345
J1, J2: Conn_01x03; PinHeader_1x03_P2.54mm_Vertical; LCSC Part C52016391
R1, R2: 27.4R; R_0402_1005Metric; LCSC Part C31439
R3: DNF; R_0402_1005Metric
R4, R5: 1K; R_0402_1005Metric; LCSC Part C11702
R6, R7, R14, R15, R16, R17, R18: 5.1K; R_0402_1005Metric; LCSC Part C25905
R8, R9, R10, R11, R12, R13: 100R; R_0402_1005Metric; LCSC Part C25076
SW1: TS-1088-AR02016; SW-SMD_L3.9-W3.0-P4.45; LCSC Part C720477
TP1, TP2, TP3, TP4, TP5, TP6, TP7: TestPoint; TestPoint_Pad_1.0x1.0mm
U1: RP2040; QFN-56-1EP_7x7mm_P0.4mm_EP3.2x3.2mm; LCSC Part C2040
U2: W25Q16JVUXIQ; USON-8_L3.0-W2.0-P0.50-BL-EP; LCSC Part C2843335
U3: LP5907MFX-3.0/NOPB; SOT-23-5_L3.0-W1.7-P0.95-LS2.8-BL; LCSC Part C475492
U4, U5: 74AUP1T17GWH; TSSOP-5_L2.1-W1.3-P0.65-LS2.2-BR; LCSC Part C545951
USB1: TYPE-C 16PIN 2MD(073); USB-C-SMD_TYPE-C-6PIN-2MD-073; LCSC Part C2765186
Y1: Crystal_GND24; Crystal_SMD_Abracon_ABM8G-4Pin_3.2x2.5mm; LCSC Part C20625731

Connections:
+1V1: C9.1, C10.1, C11.1, U1.23 (DVDD), U1.45 (VREG_VOUT), U1.50 (DVDD)
+3V3: C1.1, C2.1, C3.1, C4.1, C5.1, C6.1, C7.1, C8.1, C12.1, C16.1, C17.1, C18.1, R3.2, TP2.1, U1.1 (IOVDD), U1.10 (IOVDD), U1.22 (IOVDD), U1.33 (IOVDD), U1.42 (IOVDD), U1.43 (ADC_AVDD), U1.44 (VREG_IN), U1.48 (USB_VDD), U1.49 (IOVDD), U2.8 (VCC), U3.5 (OUT), U4.5 (VCC), U5.5 (VCC)
/GPIO8: R8.2, U1.11 (GPIO8)
/GPIO9: U1.12 (GPIO9), U4.4 (Y)
/GPIO14: R9.2, U1.17 (GPIO14)
/GPIO15: R12.2, U1.18 (GPIO15)
/GPIO16: R11.2, U1.27 (GPIO16)
/GPIO17: U1.28 (GPIO17), U5.4 (Y)
/QSPI_SCLK: U1.52 (QSPI_SCLK), U2.6 (CLK)
/QSPI_SD0: U1.53 (QSPI_SD0), U2.5 (DI/IO_{0})
/QSPI_SD1: U1.55 (QSPI_SD1), U2.2 (DO/IO_{1})
/QSPI_SD2: U1.54 (QSPI_SD2), U2.3 (~WP/IO_{2})
/QSPI_SD3: U1.51 (QSPI_SD3), U2.7 (~HOLD/~RESET/IO_{3})
/QSPI_SS: R3.1, R4.1, U1.56 (QSPI_SS), U2.1 (~CS)
/RUN: TP5.1, U1.26 (RUN)
/RX0_STAT: R18.1, U1.7 (GPIO5)
/RX1_STAT: R16.1, U1.30 (GPIO19)
/STAT: R14.1, U1.40 (GPIO28_ADC2)
/SWCLK: TP3.1, U1.24 (SWCLK)
/SWD: TP4.1, U1.25 (SWD)
/TX0_STAT: R17.1, U1.6 (GPIO4)
/TX1_STAT: R15.1, U1.29 (GPIO18)
/USB_D+: R1.1, USB1.6 (DP1), USB1.8 (DP2)
/USB_D-: R2.1, USB1.5 (DN2), USB1.7 (DN1)
/USB_DM: R2.2, U1.46 (USB_DM)
/USB_DP: R1.2, U1.47 (USB_DP)
GND: C1.2, C2.2, C3.2, C4.2, C5.2, C6.2, C7.2, C8.2, C9.2, C10.2, C11.2, C12.2, C13.2, C14.2, C15.2, C16.2, C17.2, C18.2, D1.1 (K), D2.1 (K), D3.1 (K), D4.1 (K), D5.1 (K), J1.2, J2.2, R6.2, R7.2, SW1.1, TP6.1, TP7.1, U1.19 (TESTEN), U1.57 (GND), U2.4 (GND), U2.9 (EP), U3.2 (GND), U4.3 (GND), U5.3 (GND), USB1.1 (GND), USB1.12 (GND), USB1.13 (SHELL), USB1.14 (SHELL), Y1.2, Y1.4
unnamed: C14.1, R5.2, Y1.3
unnamed: D1.2 (A), R14.2
unnamed: D2.2 (A), R15.2
unnamed: D3.2 (A), R16.2
unnamed: D4.2 (A), R17.2
unnamed: D5.2 (A), R18.2
unnamed: J1.1, R8.1
unnamed: J1.3, R9.1, R10.2
unnamed: J2.1, R11.1
unnamed: J2.3, R12.1, R13.2
unnamed: R4.2, SW1.2
unnamed: C13.1, U1.20 (XIN), Y1.1
unnamed: R5.1, U1.21 (XOUT)
unnamed: R10.1, U4.2 (A)
unnamed: R13.1, U5.2 (A)
unnamed: R7.1, USB1.4 (CC1)
unnamed: R6.1, USB1.10 (CC2)
VBUS: C15.1, TP1.1, U3.1 (IN), U3.3 (EN), USB1.2 (VBUS), USB1.11 (VBUS)

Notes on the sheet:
UART
UART1TX
UART1RX
-Status Indicator - UART Read/Write Indicator - DBUG Read/Write Indicator
UART0RX
DBUG
UART0TX

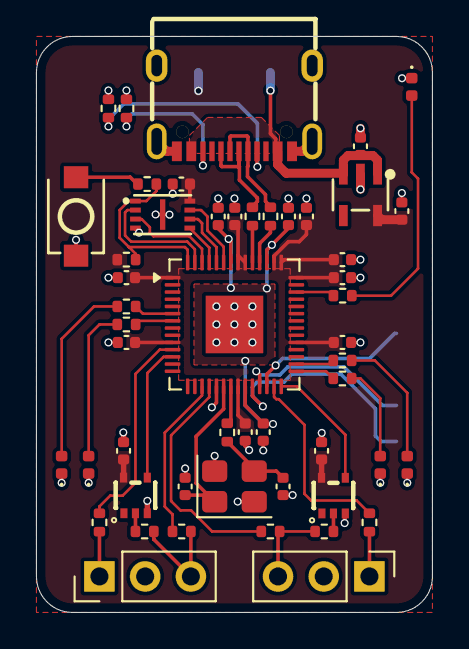
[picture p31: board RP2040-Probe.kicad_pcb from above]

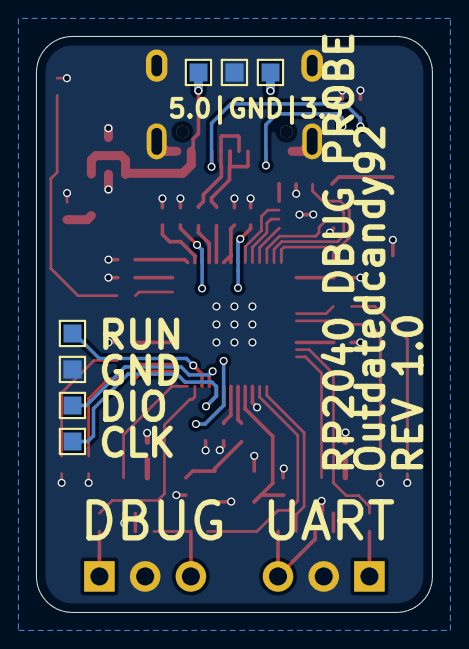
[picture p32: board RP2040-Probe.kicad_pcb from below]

Board: 2 copper layers, 22.0 x 32.0 mm, 58 parts (7 on the bottom side), 45 nets.
